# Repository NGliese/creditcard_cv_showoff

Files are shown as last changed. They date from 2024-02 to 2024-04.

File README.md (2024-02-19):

This Dockerfile installs the ESP-IDF dependencies, installs the python3-venv package, clones the ESP-IDF repository, sets the environment variables, sets the working directory to /app, copies the project files into the container, and builds the project using idf.py.

# Prerequisites
1) install docker
It is recommended to install Docker using the convenience script. See the detailed instructions for the installation on the Docker website:
    https://docs.docker.com/engine/install/ubuntu/#install-using-the-convenience-script

    Tip: preview script steps before running

    You can run the script with the --dry-run option to learn what steps the script will run when invoked:

    $ curl -fsSL https://get.docker.com -o get-docker.sh
    $ sudo sh ./get-docker.sh --dry-run

    To install the script, after reviewing, run the script without the --dry-run option:
    $ curl -fsSL https://get.docker.com -o get-docker.sh
    $ sudo sh ./get-docker.sh

2) install git

To use this Dockerfile, create a new directory for your ESP32 project and copy the Dockerfile into it. Then, copy your project files into the same directory and run the following command to build the Docker image:

docker build -t esp32_plc_mock2 .

Replace esp32_plc_mock2 with the name you want to give your Docker image.

Once the Docker image is built, you can run the following command to start a new container and build your project:

docker run -it --device=/dev/ttyUSB0 -v $(pwd):/app esp32_plc_mock2

This command starts a new container with the esp32_plc_mock2 image, mounts the current directory ($(pwd)) as a volume inside the container, and sets the working directory to /app. You can then run idf.py commands inside the container to build and flash your project.

# see the makefile for more details

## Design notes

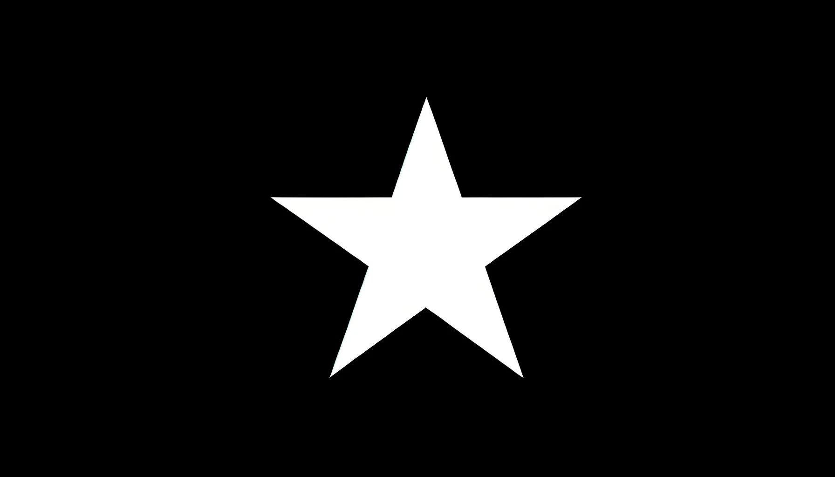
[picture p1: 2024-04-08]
img/star.png

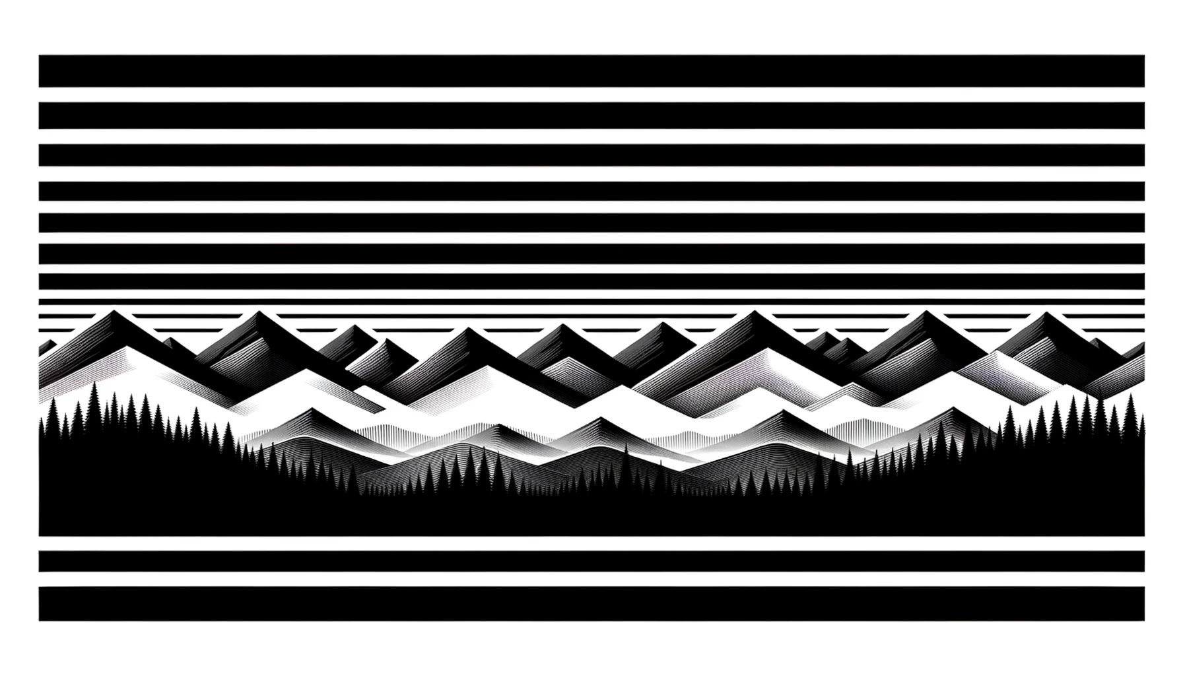
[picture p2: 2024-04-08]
img/stripes.png

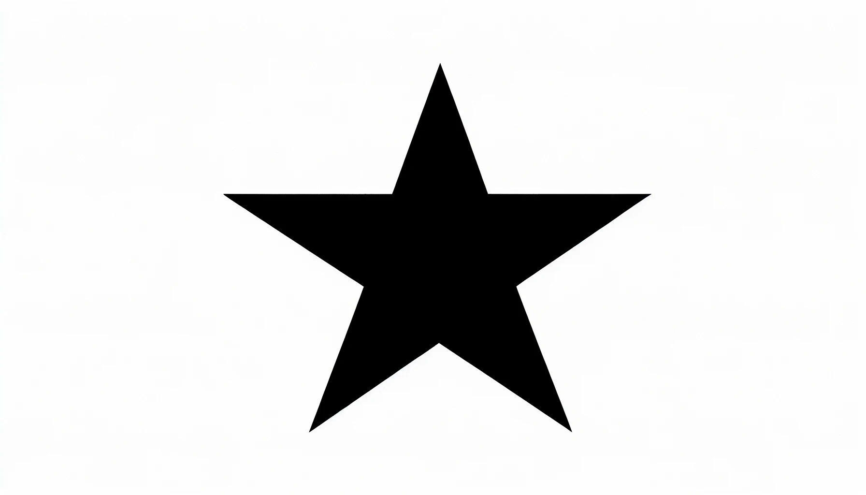
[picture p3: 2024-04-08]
img/start2.png

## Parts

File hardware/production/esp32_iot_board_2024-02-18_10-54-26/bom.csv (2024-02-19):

Designator | Footprint | Quantity | Value | LCSC Part #
C1, C10, C14, C2, C6, C9 | 1206 | 6 | 100nf | C77502
C11, C12, C13, C16, C17, C18, C19, C20 | 0603 | 8 | 1u | C559292
C15 | 1206 | 1 | 22uf | C304004
C3 | 1206 | 1 | 4u7 | C91602
C4, C5, C7, C8 | 1206 | 4 | 22u | C304004
D4 | 1206 | 1 | LED
F2 | 1206 | 1 | Polyfuse 1A | C66453
FB1 | 0603 | 1 | BLM21PG221 | C85840
J1 | USB_C_Receptacle_HRO_TYPE-C-31-M-12 | 1 | USB_C_Receptacle_USB2.0 | C2760486
J2 | PinHeader_1x07_P2.54mm_Vertical | 1 | Conn_01x07
Q1 | SOT-363_SC-70-6 | 1 | UMH3N | C62892
R1, R2 | 1206 | 2 | 5k1 | C212533
R11, R7, R8 | 1206 | 3 | 10k | C118075
R3 | 0603 | 1 | 10k | C384294
R4, R5, R6, R9 | 1206 | 4 | 1k | C131398
SW1, SW2 | SW_Push_1P1T_NO_6x6mm_H9.5mm | 2 | SW_SPST | C221869
U1 | ESP32-WROOM-32D | 1 | ESP32-WROOM-32D | C473012
U2 | SOT-666 | 1 | USBLC6-2P6 | C2827693
U3 | QFN-24-1EP_4x4mm_P0.5mm_EP2.6x2.6mm | 1 | CP2104 | C47742
U5 | NHD-C12832A1Z-FSRGB | 1 | NHD-C12832A1Z-FSRGB
U6 | SOT-223-3_TabPin2 | 1 | TLV1117LV-3.3 | C15578

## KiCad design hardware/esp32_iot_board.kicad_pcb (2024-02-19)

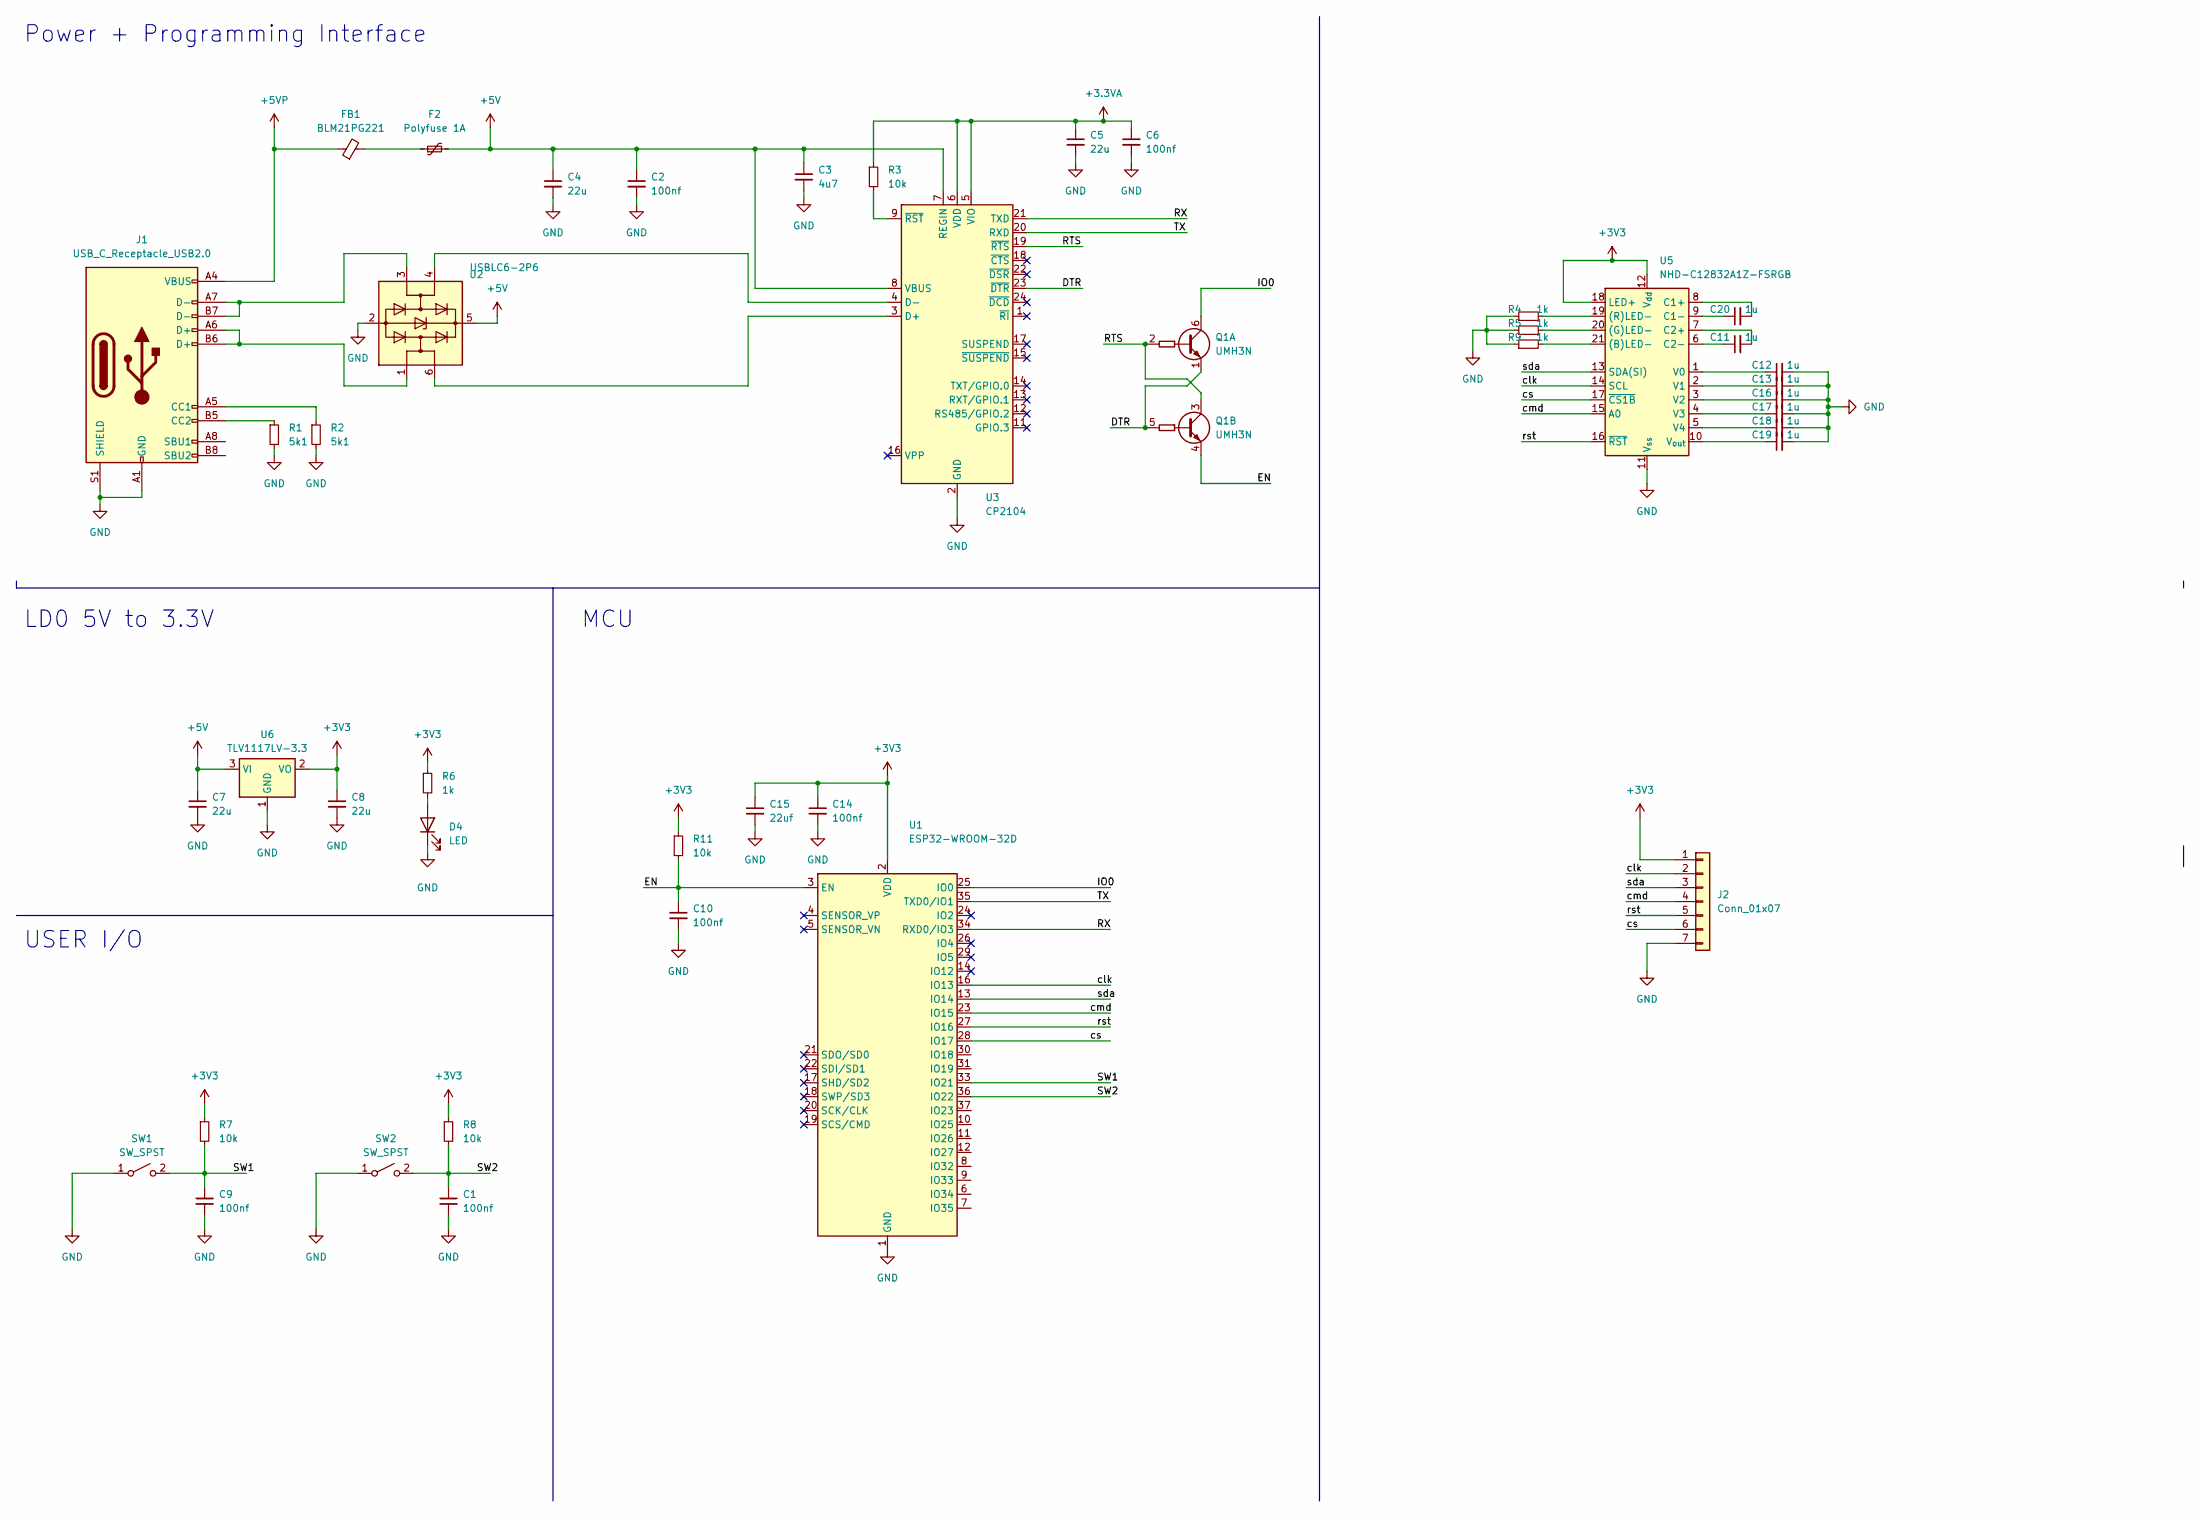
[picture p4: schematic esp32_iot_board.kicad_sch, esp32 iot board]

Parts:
C1, C2, C6, C9, C10, C14: 100nf; C_1206_3216Metric; LCSC C77502
C3: 4u7; C_1206_3216Metric; LCSC C91602
C4, C5, C7, C8: 22u; C_1206_3216Metric; LCSC C304004
C11, C12, C13, C16, C17, C18, C19, C20: 1u; C_0603_1608Metric; LCSC C559292
C15: 22uf; C_1206_3216Metric; LCSC C304004
D4: LED; LED_1206_3216Metric
F2: Polyfuse 1A; Fuse_1206_3216Metric_Pad1.42x1.75mm_HandSolder; LCSC C66453
FB1: BLM21PG221; L_0603_1608Metric_Pad1.05x0.95mm_HandSolder; LCSC C85840
J1: USB_C_Receptacle_USB2.0; USB_C_Receptacle_HRO_TYPE-C-31-M-12; LCSC C2760486
J2: Conn_01x07; PinHeader_1x07_P2.54mm_Vertical
Q1: UMH3N; SOT-363_SC-70-6; LCSC C62892
R1, R2: 5k1; R_1206_3216Metric; LCSC C212533
R3: 10k; R_0603_1608Metric; LCSC C384294
R4, R5, R6, R9: 1k; R_1206_3216Metric; LCSC C131398
R7, R8, R11: 10k; R_1206_3216Metric; LCSC C118075
SW1, SW2: SW_SPST; SW_Push_1P1T_NO_6x6mm_H9.5mm; LCSC C221869
U1: ESP32-WROOM-32D; LCSC C473012
U2: USBLC6-2P6; SOT-666; LCSC C2827693
U3: CP2104; QFN-24-1EP_4x4mm_P0.5mm_EP2.6x2.6mm; LCSC C47742
U5: NHD-C12832A1Z-FSRGB
U6: TLV1117LV-3.3; SOT-223-3_TabPin2; LCSC C15578

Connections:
+3.3VA: C5.1, C6.1, R3.1, U3.5 (VIO), U3.6 (VDD)
+3V3: C8.1, C14.1, C15.1, J2.1, R6.1, R7.1, R8.1, R11.1, U1.2 (VDD), U5.12 (V_{dd}), U5.18 (LED+), U6.2 (VO)
+5V: C2.1, C3.1, C4.1, C7.1, F2.2, U2.5 (VBUS), U3.7 (REGIN), U3.8 (VBUS), U6.3 (VI)
+5VP: FB1.1, J1.A4 (VBUS), J1.A9 (VBUS), J1.B4 (VBUS), J1.B9 (VBUS)
/DTR: Q1.1 (E1), Q1.5 (B2), U3.23 (~DTR)
/EN: C10.1, Q1.4 (E2), R11.2, U1.3 (EN)
/IO0: Q1.6 (C1), U1.25 (IO0)
/RTS: Q1.2 (B1), Q1.3 (C2), U3.19 (~RTS)
/RX: U1.34 (RXD0/IO3), U3.21 (TXD)
/SW1: C9.1, R7.2, SW1.2 (B), U1.33 (IO21)
/SW2: C1.1, R8.2, SW2.2 (B), U1.36 (IO22)
/TX: U1.35 (TXD0/IO1), U3.20 (RXD)
/clk: J2.2, U1.16 (IO13), U5.14 (SCL)
/cmd: J2.4, U1.23 (IO15), U5.15 (A0)
/cs: J2.6, U1.28 (IO17), U5.17 (~CS1B)
/rst: J2.5, U1.27 (IO16), U5.16 (~RST)
/sda: J2.3, U1.13 (IO14), U5.13 (SDA(SI))
GND: C1.2, C2.2, C3.2, C4.2, C5.2, C6.2, C7.2, C8.2, C9.2, C10.2, C12.2, C13.2, C14.2, C15.2, C16.2, C17.2, C18.2, C19.2, D4.1 (K), J1.A1 (GND), J1.A12 (GND), J1.B1 (GND), J1.B12 (GND), J1.S1 (SHIELD), J2.7, R1.2, R2.2, R4.1, R5.1, R9.1, SW1.1 (A), SW2.1 (A), U1.1 (GND), U1.15 (GND), U1.38 (GND), U1.39 (GND), U2.2 (GND), U3.2 (GND), U3.25 (GND), U5.11 (V_{ss}), U6.1 (GND)
unnamed: D4.2 (A), R6.2
unnamed: F2.1, FB1.2
unnamed: J1.A5 (CC1), R2.1
unnamed: J1.B5 (CC2), R1.1
unnamed: J1.A6 (D+), J1.B6 (D+), U2.1 (I/O1)
unnamed: J1.A7 (D-), J1.B7 (D-), U2.3 (I/O2)
unnamed: U2.6 (I/O1), U3.3 (D+)
unnamed: U2.4 (I/O2), U3.4 (D-)
unnamed: R3.2, U3.9 (~RST)
unnamed: R9.2, U5.21 ((B)LED-)
unnamed: R5.2, U5.20 ((G)LED-)
unnamed: R4.2, U5.19 ((R)LED-)
unnamed: C20.2, U5.8 (C1+)
unnamed: C20.1, U5.9 (C1-)
unnamed: C11.2, U5.7 (C2+)
unnamed: C11.1, U5.6 (C2-)
unnamed: C12.1, U5.1 (V0)
unnamed: C13.1, U5.2 (V1)
unnamed: C16.1, U5.3 (V2)
unnamed: C17.1, U5.4 (V3)
unnamed: C18.1, U5.5 (V4)
unnamed: C19.1, U5.10 (V_{out})

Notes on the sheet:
LD0 5V to 3.3V
Power + Programming Interface
MCU
USER I/O

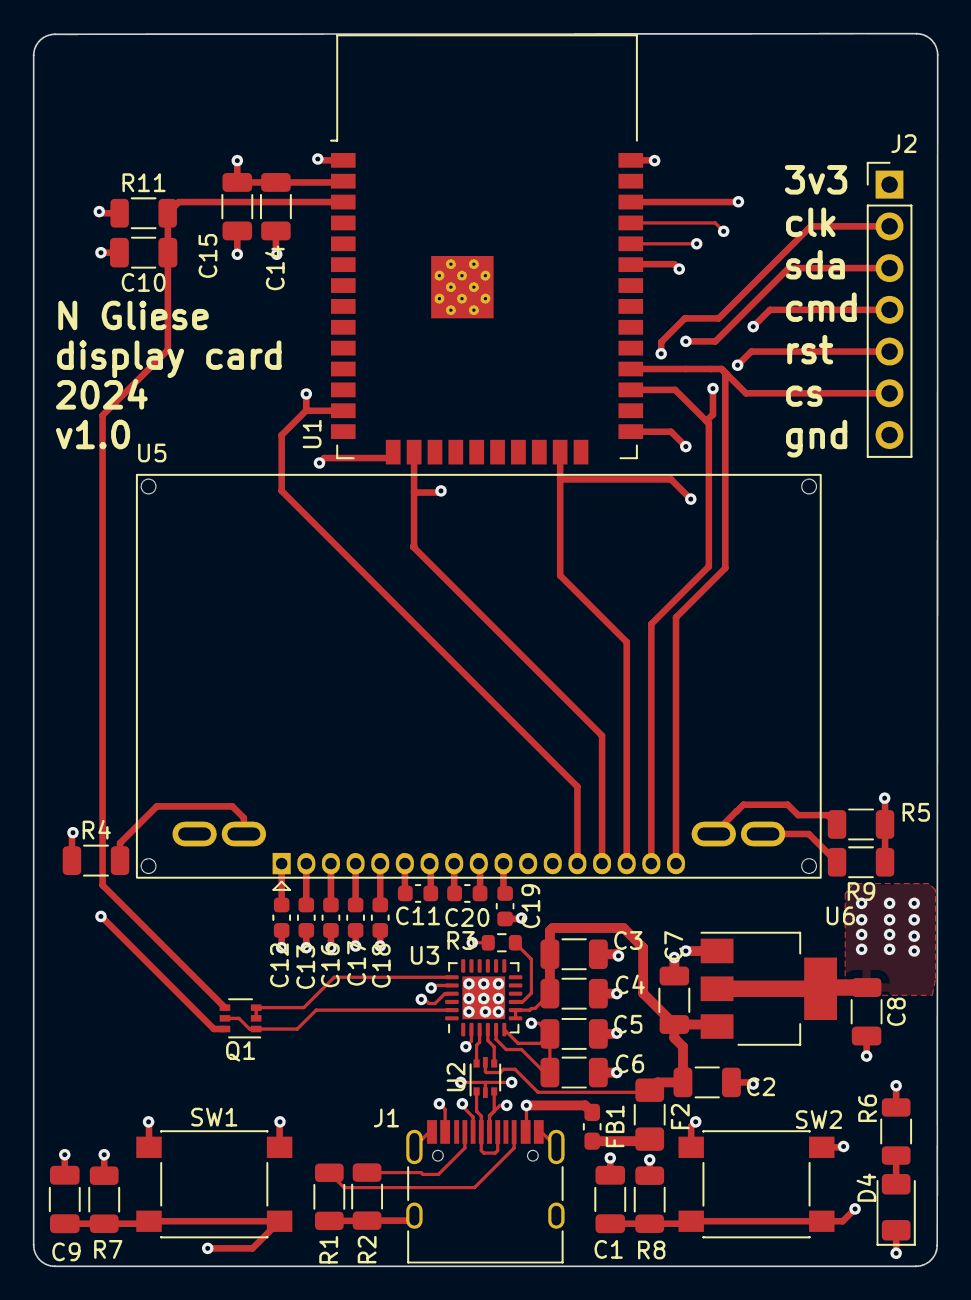
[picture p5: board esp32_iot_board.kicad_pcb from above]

Board: 4 copper layers, 55.0 x 75.0 mm, 43 parts (0 on the bottom side), 40 nets.

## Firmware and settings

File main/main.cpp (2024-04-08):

/* pthread/std::thread example

   This example code is in the Public Domain (or CC0 licensed, at your option.)

   Unless required by applicable law or agreed to in writing, this
   software is distributed on an "AS IS" BASIS, WITHOUT WARRANTIES OR
   CONDITIONS OF ANY KIND, either express or implied.
*/

#include <driver/gpio.h>
#include <esp_err.h>
#include <esp_log.h>

#include <button_test.hpp>
#include <iostream>
#include <lcd_test.hpp>

#include "sdkconfig.h"

extern "C" void app_main(void) {
  std::cout << "Hello, World!" << std::endl;
  std::cout << "This is ESP32 chip with " << CONFIG_IDF_TARGET << " chip"
            << std::endl;

  /*
    RUN THE EXAMPLES BELOW ONE AT A TIME
  */

   button_test test;
   test.run_controlled_lcd();
  //  test.run();
  //lcd_test lcd;
  // lcd.run();
  // lcd.test_io();
  //lcd.test_spi();
  std::cout << "Stopping program" << std::endl;
}

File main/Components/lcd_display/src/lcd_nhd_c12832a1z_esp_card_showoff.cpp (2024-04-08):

/***********************************************************************************************+
 *  \brief      BRIEF TEXT
 *  \par
 *  \par        @DETAILS
 *
 *
 *  \li         LIMITATION-TO-CLASS
 *  \li         LIMITATION-TO-CLASS
 *
 *  \note       ANY RELEVANT NOTES
 *
 *  \file       lcd_nhd_c12832a1z_esp_card_showoff.cpp
 *  \author     N.G Pedersen <nikolajgliese@tutanota.com>
 *  \version    1.0
 *  \date       2024
 *  \copyright  --
 *
 *
 ***********************************************************************************************/

#include "../include/lcd_nhd_c12832a1z_esp_card_showoff.hpp"
#include "../include/lcd_data.hpp"

//#define DEBUG // default uncommeted

#ifdef DEBUG
static const char* LOG_TAG = "lcd_nhd_c12832a1z_esp_card_showoff";
#endif

/*
    COMMANDS FOR THE DISPLAY
*/
#define CMD_DISPLAY_OFF 0xAE
#define CMD_DISPLAY_ON 0xAF
#define CMD_SET_DISP_START_LINE 0x40
#define CMD_SET_PAGE 0xB0
#define CMD_SET_COLUMN_UPPER 0x10
#define CMD_SET_COLUMN_LOWER 0x00
#define CMD_SET_ADC_NORMAL 0xA0
#define CMD_SET_ADC_REVERSE 0xA1
#define CMD_SET_DISP_NORMAL 0xA6
#define CMD_SET_DISP_REVERSE 0xA7
#define CMD_SET_ALLPTS_NORMAL 0xA4
#define CMD_SET_ALLPTS_ON 0xA5
#define CMD_SET_BIAS_9 0xA2
#define CMD_SET_BIAS_7 0xA3
#define CMD_RMW 0xE0
#define CMD_RMW_CLEAR 0xEE
#define CMD_INTERNAL_RESET 0xE2
#define CMD_SET_COM_NORMAL 0xC0
#define CMD_SET_COM_REVERSE 0xC8
#define CMD_SET_POWER_CONTROL 0x2F
#define CMD_SET_RESISTOR_RATIO 0x21
#define CMD_SET_VOLUME_FIRST 0x81
#define CMD_SET_VOLUME_SECOND 0x20
#define CMD_SET_STATIC_OFF 0xAC
#define CMD_SET_STATIC_ON 0xAD
#define CMD_SET_STATIC_REG 0x0
#define CMD_SET_BOOSTER_FIRST 0xF8
#define CMD_SET_BOOSTER_234 0
#define CMD_SET_BOOSTER_5 1
#define CMD_SET_BOOSTER_6 3
#define CMD_NOP 0xE3
#define CMD_TEST 0xF0

lcd_nhd_c12832a1z_esp_card_showoff::lcd_nhd_c12832a1z_esp_card_showoff(
    const HAL_GPIO_ESP32::pin& rst_pin, 
    const HAL_GPIO_ESP32::pin& cmd_pin)
    : m_rst_pin{rst_pin},
      m_cmd_pin{cmd_pin}, m_spi{IO_SCL_PIN, IO_SDA_PIN, -1, CS_PIN, 10* 1000*1000} {



      }

lcd_nhd_c12832a1z_esp_card_showoff::~lcd_nhd_c12832a1z_esp_card_showoff() {}

bool lcd_nhd_c12832a1z_esp_card_showoff::init() {
#ifdef DEBUG
  ESP_LOGI(LOG_TAG, "init called");
#endif
  // set all pins to output
  m_rst_pin.setToOutput();
  m_cmd_pin.setToOutput();
  // set rst and cs to low
  m_rst_pin.setLow();
  m_cmd_pin.setLow();
  m_spi.open();
  // wait 100 ms

  Timeservice::wait_ms(100);
  m_rst_pin.setHigh();
  // wait 100 ms
  Timeservice::wait_ms(100);

/*
  // initialize the display
  send_command(CMD_DISPLAY_OFF);  // display off
  Timeservice::wait_ms(100);

  send_command(CMD_SET_DISP_START_LINE);  // set display start line
  Timeservice::wait_ms(100);

  send_command(CMD_SET_PAGE);  // set page
  Timeservice::wait_ms(100);

  send_command(CMD_SET_ADC_NORMAL);  // set adc normal
  Timeservice::wait_ms(100);

  send_command(CMD_SET_DISP_NORMAL);  // set display normal
  Timeservice::wait_ms(100);

  send_command(CMD_SET_COM_NORMAL);  // set com normal
  Timeservice::wait_ms(100);

  send_command(CMD_SET_BIAS_9);  // set bias 9
  Timeservice::wait_ms(100);

  send_command(CMD_SET_POWER_CONTROL);  // set power control
  Timeservice::wait_ms(100);

  send_command(CMD_DISPLAY_ON);  // display on
  Timeservice::wait_ms(100);
*/

// lets follow the guide from the data sheet

  send_command(CMD_SET_ADC_NORMAL); // ADC select
  send_command(CMD_DISPLAY_OFF); // Display OFF
  send_command(CMD_SET_COM_REVERSE); // COM direction scan
  send_command(CMD_SET_BIAS_9); // LCD bias set
  send_command(CMD_SET_POWER_CONTROL); // Power Control set
  send_command(CMD_SET_RESISTOR_RATIO); // Resistor Ratio Set
  send_command(CMD_SET_VOLUME_FIRST); // Electronic Volume Command (set contrast) Double Btye: 1 of 2
  send_command(CMD_SET_VOLUME_SECOND); // Electronic Volume value (contrast value) Double Byte: 2 of 2
  // costum commands
  //send_command(CMD_SET_DISP_REVERSE); // Display reverse
  send_command(CMD_DISPLAY_ON); // Display ON
  
  // we are now initialized
  is_init = true;

  return true;
}

bool lcd_nhd_c12832a1z_esp_card_showoff::deinit() {
#ifdef DEBUG
  ESP_LOGI(LOG_TAG, "deinit called");
#endif
  m_spi.close();
  return true;
}

bool lcd_nhd_c12832a1z_esp_card_showoff::clear() {
#ifdef DEBUG
  ESP_LOGI(LOG_TAG, "clear called");
#endif

   unsigned char page = CMD_SET_PAGE; // page address
  send_command(CMD_DISPLAY_OFF); // Display OFF
  send_command(CMD_SET_DISP_START_LINE); // Display start address + 0x40
  uint8_t lcd_string[1] = {0x00}; // 2 bytes of data
  for (unsigned int i = 0; i < 4; i++)
  {                   // 32pixel display / 8 pixels per page = 4 pages
    send_command(page); // send page address
    send_command(CMD_SET_COLUMN_UPPER); // column address upper 4 bits + 0x10
    send_command(CMD_SET_COLUMN_LOWER); // column address lower 4 bits + 0x00
    for (unsigned int j = 0; j < 128; j++)
    {                          // 128 columns wide
      write(lcd_string,1); // send picture data
     // lcd_string[0] = ~lcd_string[0]; // invert data
    }
    page++; // after 128 columns, go to next page
  }
  send_command(CMD_DISPLAY_ON);
  return true;

  return true;
}

bool lcd_nhd_c12832a1z_esp_card_showoff::write(const uint8_t* data,
                                               const size_t size) {
#ifdef DEBUG
  ESP_LOGI(LOG_TAG, "write called");
#endif

  // set cmd pin to high
  m_cmd_pin.setHigh();

  Timeservice::wait_us(10);
  // copy data
  
  m_spi.write(data, size);

  return true;
}

bool lcd_nhd_c12832a1z_esp_card_showoff::setCursor(int x, int y) {
#ifdef DEBUG
  ESP_LOGI(LOG_TAG, "setCursor called");
#endif

  return true;
}

bool lcd_nhd_c12832a1z_esp_card_showoff::send_command(const uint8_t data) {
#ifdef DEBUG
  ESP_LOGI(LOG_TAG, "send_command called");
#endif
  // set cmd pin to low
  m_cmd_pin.setLow();
  Timeservice::wait_us(10);
  // copy data
  uint8_t data_copy = data;
  m_spi.write(&data_copy, 1);

  // set cmd pin to high
  m_cmd_pin.setHigh();

  return true;
}
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

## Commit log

2024-02-19 hardware init
    [bom.csv, designators.csv, esp32_iot_board.kicad_pcb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]
2024-02-25 included button with isr
2024-03-12 added tests to lcd gpio and timer
